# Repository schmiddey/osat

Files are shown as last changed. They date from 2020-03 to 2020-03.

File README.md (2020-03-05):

# osat
Open Source Airsoft Target, WLAN-based Smart Target System

# Overview
The idea of the target system is, that you have one base station (Raspi Pi as WLAN AP) and many target satelites.
The Targets contain a Wemos D1 mini, a Neopixel LED, and a Piezo sensor behind a Polycarbonate plate.

More info is coming !!!

# Process
Currently only the firmware and maybe the hardware is ready or alpha state :)

The Software for the Raspi has to be done next.

note: this was my first try in hardware desigen (KiCAD) and CAD (OpenSCAD) so lets see :)

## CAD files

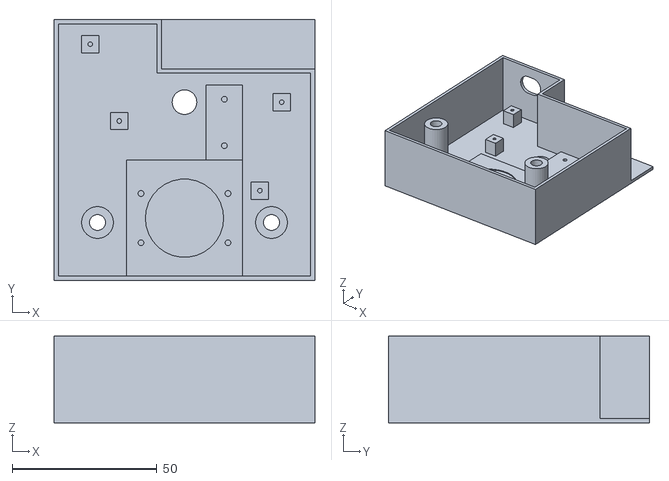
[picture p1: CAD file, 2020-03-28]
cad/stl/osat_base_v1_thinner.stl
90.0 x 90.0 x 30.0

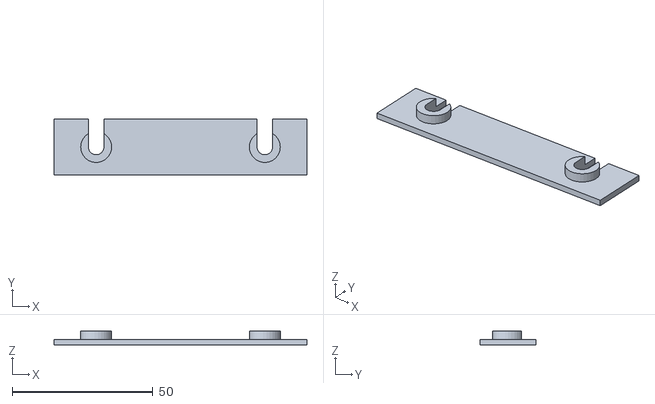
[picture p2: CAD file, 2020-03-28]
cad/stl/osat_base_mount_helper.stl
90.0 x 20.0 x 5.00

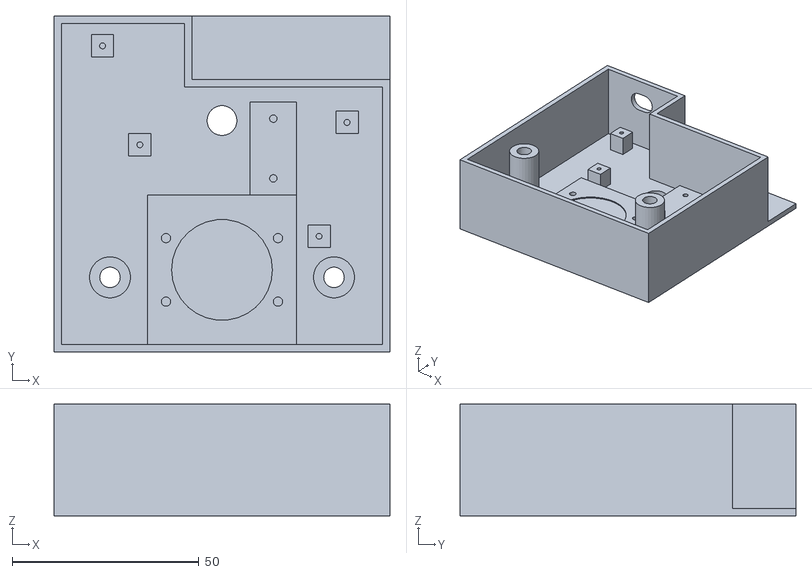
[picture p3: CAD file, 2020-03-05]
cad/stl/osat_base_v1.stl
90.0 x 90.0 x 30.0

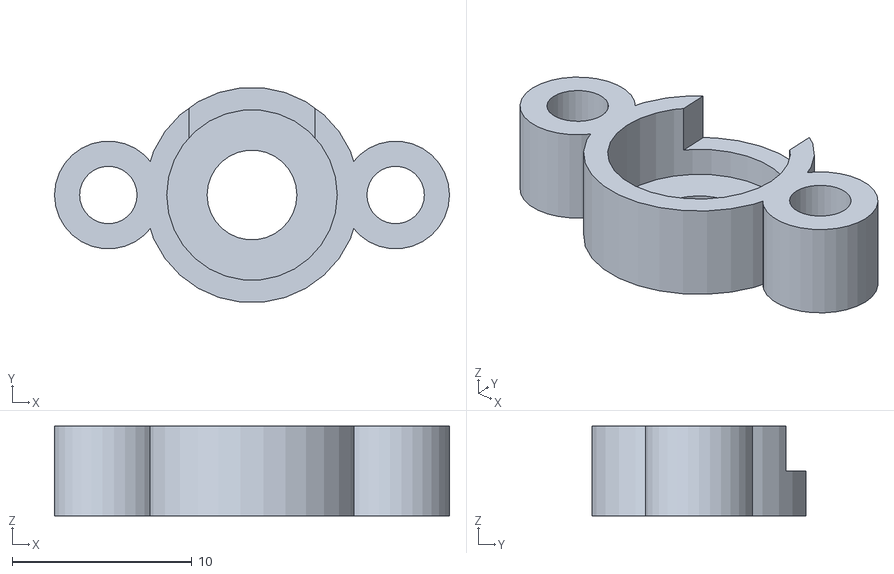
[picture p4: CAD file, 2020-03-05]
cad/stl/WS2812_single_led_mount.stl
22.0 x 11.9 x 5.00

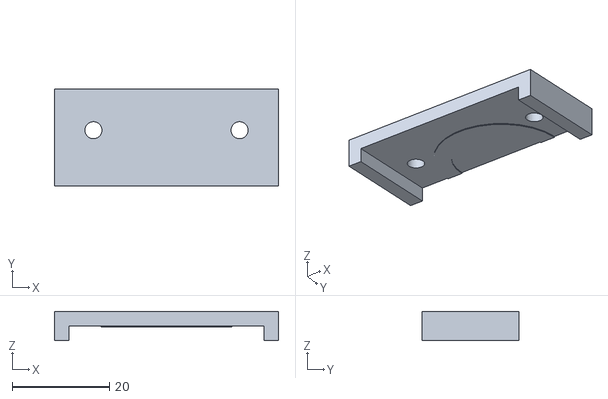
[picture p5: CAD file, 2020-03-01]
cad/stl/osat_piezo_fix.stl
46.0 x 20.0 x 6.00

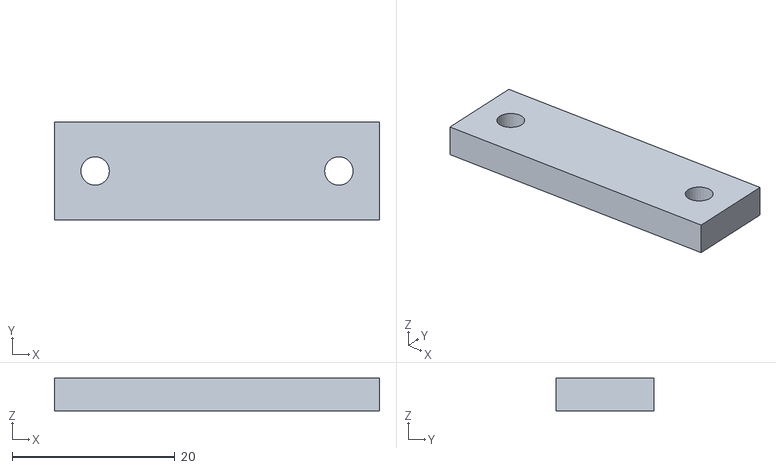
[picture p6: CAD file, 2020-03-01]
cad/stl/osat_piezo_solder_fix.stl
40.0 x 12.0 x 4.00

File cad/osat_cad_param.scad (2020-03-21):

x_length = 90;
y_length = 90;
z_length = 30;

wall_thickness = 1.5;
bottom_thickness = 2;

battery_x_length = 53;
battery_y_length = 17;


glass_mount_hole_diameter = 5.5;
glass_mount_hole_x_dist   = 15;
glass_mount_hole_y_dist   = 20;

piezo_mount_width = 40;
piezo_mount_height = 6;
piezo_y_dist      = 20;
piezo_solder_fix_hole_diameter = 2;
piezo_solder_fix_hole_diameter_2 = 3.5;

piezo_height_step    = 0.2;
piezo_diameter       = 27;
piezo_diameter_inner = 20;

led_mount_width      = 12.5;
led_mount_height     = 5;
led_cable_duct_width = 4;

//param solder mount
x_lenth_solder_mount = 12;


//param piezo_fix
y_length_piezo_fix = 20;


$fs = 0.01;

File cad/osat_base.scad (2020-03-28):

include<osat_cad_param.scad>


union()
{
  difference()
  {
    //main frame
    union()
    {
      difference()
      {
        cube([x_length, y_length, z_length], center = false);
        translate([wall_thickness,wall_thickness,wall_thickness])  cube([x_length - wall_thickness * 2, y_length - wall_thickness * 2 - battery_y_length, 90], center = false);
        translate([wall_thickness,wall_thickness,wall_thickness])  cube([x_length - wall_thickness * 2 - battery_x_length, y_length - wall_thickness * 2, 90], center = false);

        //battery
        translate([x_length - battery_x_length,y_length - battery_y_length,wall_thickness])  cube([x_length, y_length , 90], center = false);
      }
      //mount hole stabilizer
      translate([glass_mount_hole_x_dist, glass_mount_hole_y_dist, 0]) cylinder(d=glass_mount_hole_diameter * 2, h=z_length, center=false);
      translate([x_length - glass_mount_hole_x_dist, glass_mount_hole_y_dist, 0]) cylinder(d=glass_mount_hole_diameter * 2, h=z_length, center=false);
    }

    //mount holes
    #translate([glass_mount_hole_x_dist, glass_mount_hole_y_dist, 0]) cylinder(d=glass_mount_hole_diameter, h=z_length * 2.5, center=true);
    #translate([x_length - glass_mount_hole_x_dist, glass_mount_hole_y_dist, 0]) cylinder(d=glass_mount_hole_diameter, h=z_length * 2.5, center=true);

    //hole for battery connector
    translate([x_length/2, wall_thickness + piezo_mount_width + 20, wall_thickness]) #cylinder(d=8.5, h=z_length * 2.5, center=true);

    //hole for usb conn to wemos
    translate([18,y_length, 19 + wall_thickness]){
      translate([-1.5, 0, 0]) rotate([90,0,0]) #cylinder(d=9, h=z_length, center=true);
      translate([1.5, 0, 0]) rotate([90,0,0]) #cylinder(d=9, h=z_length, center=true);
      rotate([0,90,0]) #cube([9, z_length, 3], center = true);
    }

  }


  //Piezo mount
  translate([x_length/2 - piezo_mount_width/2, wall_thickness, wall_thickness])
  {
    difference()
    {
      cube([piezo_mount_width, piezo_mount_width, piezo_mount_height], center = false);  //piezo mount base
      translate([piezo_mount_width/2, piezo_y_dist, piezo_mount_height - piezo_height_step * 2]) cylinder(d=piezo_diameter, h=100, center=false);   //piezo mount hole
      //holes for screws
      translate([piezo_mount_width/2 - 15, piezo_y_dist + 8.5, 0]) cylinder(d=piezo_solder_fix_hole_diameter, h=100, center=false);
      translate([piezo_mount_width/2 + 15, piezo_y_dist + 8.5, 0]) cylinder(d=piezo_solder_fix_hole_diameter, h=100, center=false);

      translate([piezo_mount_width/2 - 15, piezo_y_dist - 8.5, 0]) cylinder(d=piezo_solder_fix_hole_diameter, h=100, center=false);
      translate([piezo_mount_width/2 + 15, piezo_y_dist - 8.5, 0]) cylinder(d=piezo_solder_fix_hole_diameter, h=100, center=false);
    }

    //just show other stuff in base file
    %translate([0, piezo_y_dist + 8.5 - x_lenth_solder_mount/2, 20])
    {
      include<osat_piezo_solder_fix.scad>
    }

    %translate([-wall_thickness, 0, 20])
    {
      include <osat_piezo_fix.scad>;
    }


  }

  mount_hole = 1.6;

  //led mount base
  translate([x_length/2 + piezo_mount_width/2 - led_mount_width, wall_thickness + piezo_mount_width , wall_thickness])
  {
    y_length_led_mount = y_length - piezo_mount_width - battery_y_length - wall_thickness*2;
    difference()
    {
      cube([led_mount_width, y_length_led_mount - led_cable_duct_width, led_mount_height], center = false);
      translate([led_mount_width / 2, y_length_led_mount / 2 - led_cable_duct_width / 2 + 8, 0]) #cylinder(d = 2, h = led_mount_height * 2, center = false);
      translate([led_mount_width / 2, y_length_led_mount / 2 - led_cable_duct_width / 2 - 8, 0]) #cylinder(d = 2, h = led_mount_height * 2, center = false);
    }
    
    %translate([led_mount_width / 2, y_length_led_mount / 2 - led_cable_duct_width / 2 , 15]){ 
      rotate([180,0,-90]) {include <WS2812_single_led_mount.scad>}
    }   
  }

  board_mount_height = 7;
  //wemose mount
  translate([wall_thickness + 9 + 2, wall_thickness + piezo_mount_width + 40, board_mount_height/2 + wall_thickness]) 
  {
    translate([0, 0, 0]){
      difference() {
        cube([6, 6, board_mount_height], center = true);
        #cylinder(d = mount_hole, h = 30, center = true);
      }
    }
    translate([10, -26.5, 0]){
      difference(){
        cube([6, 6, board_mount_height], center = true);
        #cylinder(d = mount_hole, h = 30, center = true);
      }
    }
    //dbg wemos board
    %translate([-9, -38.5, board_mount_height/2]) cube([26.5, 43, 3], center = false); 
  }

  //dcdc mount
  translate([6 + x_length/2 + piezo_mount_width/2, glass_mount_hole_y_dist + glass_mount_hole_diameter * 2, board_mount_height/2 + wall_thickness]) 
  {
    translate([0, 0, 0]) {
      difference(){
        cube([6, 6, board_mount_height], center = true);
        #cylinder(d = mount_hole, h = 30, center = true);
      }
    } 
    translate([7.5, 30.5, 0]) {
      difference(){
        cube([6, 6, board_mount_height], center = true);
        #cylinder(d = mount_hole, h = 30, center = true);
      }
    }
    %translate([-2.45, -2.45, board_mount_height/2]) cube([17.5, 40.5, 3], center = false);  
  }



}

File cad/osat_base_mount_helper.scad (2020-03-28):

include<osat_cad_param.scad>

x_dist = x_length - glass_mount_hole_x_dist * 2;

difference()
{
  //base
  union()
  {
    cylinder(d = glass_mount_hole_diameter * 2, h = 5, center = false);
    translate([x_dist, 0, 0]) {
      cylinder(d = glass_mount_hole_diameter * 2, h = 5, center = false);
    }
    translate([(x_length - x_dist)/-2, -10, 0]){ cube([x_length, 20, 2], center = false); }
  }
  //holes

  translate([x_dist, 0, 0]) {
      cylinder(d = glass_mount_hole_diameter, h = 25, center = true);
  }
  cylinder(d = glass_mount_hole_diameter, h = 25, center = true);

  //notch
  translate([0, 15, 0]){ cube([glass_mount_hole_diameter, 30, 30], center = true); }
  translate([x_dist, 15, 0]){ cube([glass_mount_hole_diameter, 30, 30], center = true); }

}

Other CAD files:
cad/stl/osat_base_v0.stl
cad/osat_piezo_fix.scad
cad/WS2812_single_led_mount.scad
cad/osat_piezo_solder_fix.scad

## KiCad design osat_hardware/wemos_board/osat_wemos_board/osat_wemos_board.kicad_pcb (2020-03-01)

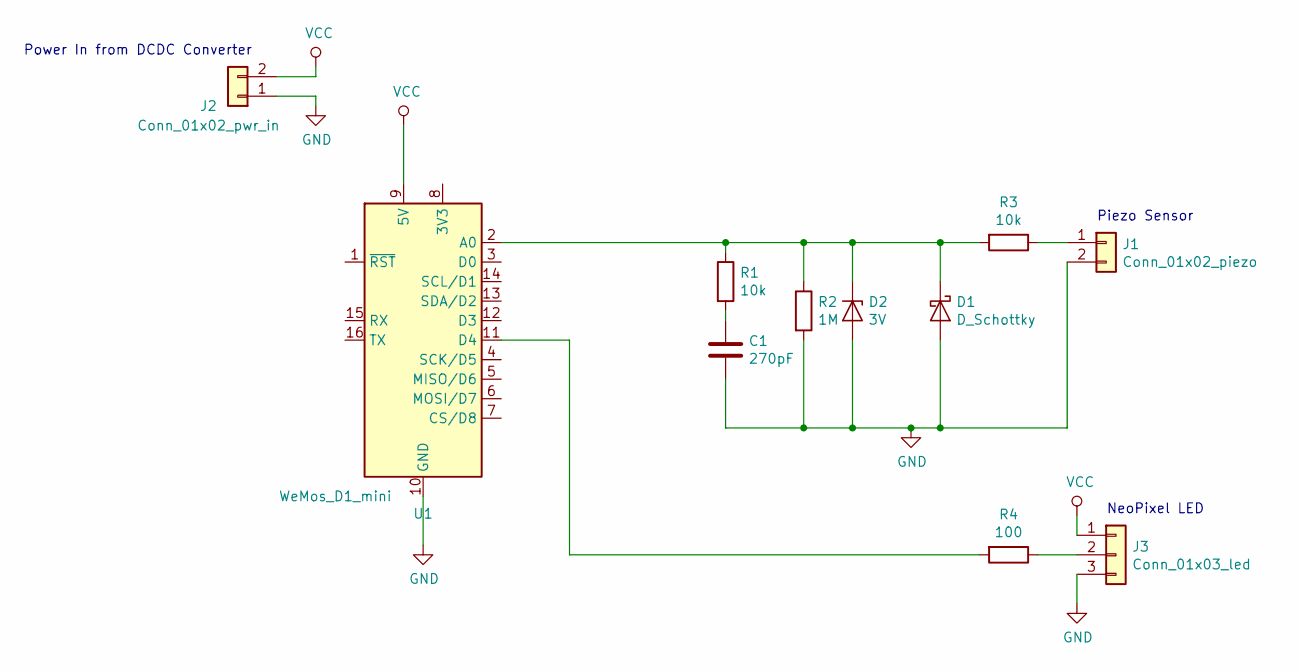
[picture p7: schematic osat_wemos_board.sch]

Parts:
C1: 270pF; C_Disc_D4.3mm_W1.9mm_P5.00mm
D1: D_Schottky; D_A-405_P2.54mm_Vertical_AnodeUp
D2: 3V; D_A-405_P2.54mm_Vertical_AnodeUp
J1: Conn_01x02_piezo; JST_EH_B2B-EH-A_1x02_P2.50mm_Vertical
J2: Conn_01x02_pwr_in; JST_EH_B2B-EH-A_1x02_P2.50mm_Vertical
J3: Conn_01x03_led; JST_EH_B3B-EH-A_1x03_P2.50mm_Vertical
R1, R3: 10k; R_Axial_DIN0204_L3.6mm_D1.6mm_P2.54mm_Vertical
R2: 1M; R_Axial_DIN0204_L3.6mm_D1.6mm_P2.54mm_Vertical
R4: 100; R_Axial_DIN0204_L3.6mm_D1.6mm_P2.54mm_Vertical
U1: WeMos_D1_mini; WEMOS_D1_mini_light

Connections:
GND: C1.1, D1.2 (A), D2.2 (A), J1.2, J2.1, J3.3, R2.2, U1.10 (GND)
unnamed: C1.2, R1.2
unnamed: D1.1 (K), D2.1 (K), R1.1, R2.1, R3.2, U1.2 (A0)
unnamed: J1.1, R3.1
unnamed: J3.2, R4.1
unnamed: R4.2, U1.11 (D4)
VCC: J2.2, J3.1, U1.9 (5V)

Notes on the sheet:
Piezo Sensor
NeoPixel LED
Power In from DCDC Converter

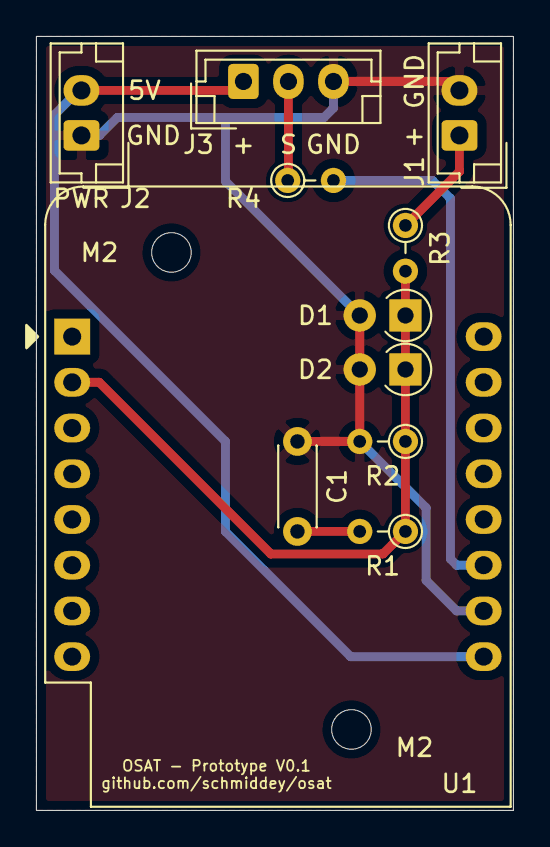
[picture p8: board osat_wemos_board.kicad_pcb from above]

Board: 2 copper layers, 26.5 x 43.0 mm, 13 parts (0 on the bottom side), 7 nets.

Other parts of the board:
M2, M2#2: MountingHole_2.2mm_M2

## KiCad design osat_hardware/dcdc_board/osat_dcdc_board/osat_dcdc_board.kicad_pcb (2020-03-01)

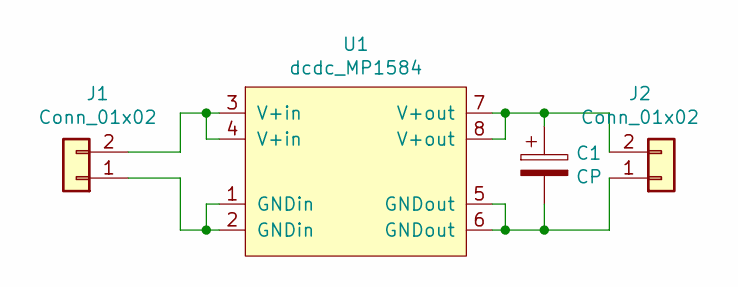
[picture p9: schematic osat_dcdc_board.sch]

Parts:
C1: CP; CP_Radial_D8.0mm_P5.00mm
J1, J2: Conn_01x02; JST_EH_B2B-EH-A_1x02_P2.50mm_Vertical
U1: dcdc_MP1584; MP1584EN_dcdc

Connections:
unnamed: C1.1, J2.2, U1.7 (V+out), U1.8 (V+out)
unnamed: C1.2, J2.1, U1.5 (GNDout), U1.6 (GNDout)
unnamed: J1.1, U1.1 (GNDin), U1.2 (GNDin)
unnamed: J1.2, U1.3 (V+in), U1.4 (V+in)

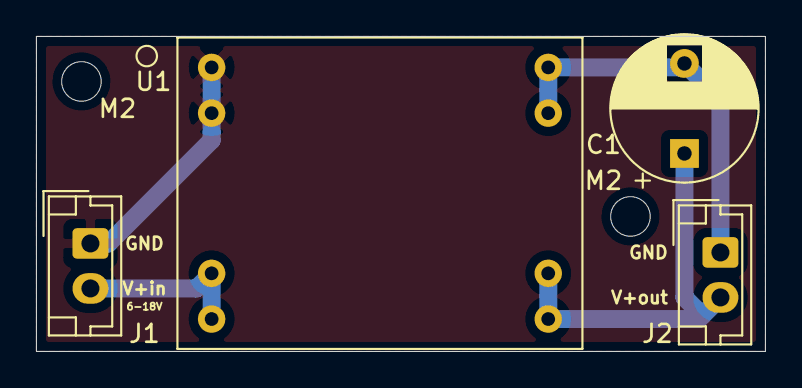
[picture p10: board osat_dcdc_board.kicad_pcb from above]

Board: 2 copper layers, 40.5 x 17.5 mm, 6 parts (0 on the bottom side), 4 nets.

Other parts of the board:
M2, M2#2: MountingHole_2.2mm_M2

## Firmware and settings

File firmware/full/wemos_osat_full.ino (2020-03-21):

#include "Arduino.h"


#include <Adafruit_NeoPixel.h>
#include <ESP8266WiFi.h>
#include <EEPROM.h>
// #include <MQTTClient.h>
#include <WiFiUdp.h>

struct OsatConfig{
  uint8_t    id         = 255;
  uint16_t   hit_thresh = 50;
  uint16_t   timeout_ms = 1500;

  String toString() const
  {
    String str("OsatConfig #id:");
    str += String(id);
    str += String(" #hit_thresh:");
    str += String(hit_thresh);
    str += String(" #timeout_ms:");
    str += String(timeout_ms);
    return str;
  }
};

// https://stackoverflow.com/questions/51731313/cross-platform-crc8-function-c-and-python-parity-check
uint8_t crc8( uint8_t *addr, uint8_t len) {
      uint8_t crc=0;
      for (uint8_t i=0; i<len;i++) {
         uint8_t inbyte = addr[i];
         for (uint8_t j=0;j<8;j++) {
             uint8_t mix = (crc ^ inbyte) & 0x01;
             crc >>= 1;
             if (mix) 
                crc ^= 0x8C;
         inbyte >>= 1;
      }
    }
   return crc;
}

namespace cfg{
  enum Config{
    ID           = 0,
    THRESH_LOW,
    THRESH_HIGH,
    TIMEOUT_LOW,
    TIMEOUT_HIGH,
    CRC,
    CFG_SIZE
  };
}



void write_osat_config(const OsatConfig& cfg)
{
  EEPROM.begin(512);

  uint8_t eeprom_data[cfg::CFG_SIZE];

  eeprom_data[cfg::ID]            = cfg.id;
  eeprom_data[cfg::THRESH_LOW]    = lowByte(cfg.hit_thresh);
  eeprom_data[cfg::THRESH_HIGH]   = highByte(cfg.hit_thresh);
  eeprom_data[cfg::TIMEOUT_LOW]   = lowByte(cfg.timeout_ms);
  eeprom_data[cfg::TIMEOUT_HIGH]  = highByte(cfg.timeout_ms);
  eeprom_data[cfg::CRC]           = crc8(eeprom_data, cfg::CFG_SIZE - 1);
  
  EEPROM.write(cfg::ID,            eeprom_data[cfg::ID]);
  EEPROM.write(cfg::THRESH_LOW,    eeprom_data[cfg::THRESH_LOW]);
  EEPROM.write(cfg::THRESH_HIGH,   eeprom_data[cfg::THRESH_HIGH]);
  EEPROM.write(cfg::TIMEOUT_LOW,   eeprom_data[cfg::TIMEOUT_LOW]);
  EEPROM.write(cfg::TIMEOUT_HIGH,  eeprom_data[cfg::TIMEOUT_HIGH]);
  EEPROM.write(cfg::CRC,           eeprom_data[cfg::CRC]);
  EEPROM.end();
}

OsatConfig read_osat_config()
{
  OsatConfig cfg;

  EEPROM.begin(512);

  uint8_t id            = EEPROM.read(cfg::ID);
  uint8_t thresh_low    = EEPROM.read(cfg::THRESH_LOW);
  uint8_t thresh_high   = EEPROM.read(cfg::THRESH_HIGH);
  uint8_t timeout_low   = EEPROM.read(cfg::TIMEOUT_LOW);
  uint8_t timeout_high  = EEPROM.read(cfg::TIMEOUT_HIGH);

  EEPROM.end();

  cfg.id = id;
  cfg.hit_thresh = word(thresh_high, thresh_low);
  cfg.timeout_ms = word(timeout_high, timeout_low);

  return cfg;
}

/**
 * @brief checks if eeprom_cfg is valid, if not, init with default
 * 
 * @return true is eeprom config is ok, false if not but now valid (with default values)
 */
bool check_osat_config()
{
  uint8_t eeprom_data[cfg::CFG_SIZE];
  
  EEPROM.begin(512);

  eeprom_data[cfg::ID]           = EEPROM.read(cfg::ID);
  eeprom_data[cfg::THRESH_LOW]   = EEPROM.read(cfg::THRESH_LOW);
  eeprom_data[cfg::THRESH_HIGH]  = EEPROM.read(cfg::THRESH_HIGH);
  eeprom_data[cfg::TIMEOUT_LOW]  = EEPROM.read(cfg::TIMEOUT_LOW);
  eeprom_data[cfg::TIMEOUT_HIGH] = EEPROM.read(cfg::TIMEOUT_HIGH);  
  eeprom_data[cfg::CRC]          = EEPROM.read(cfg::CRC);

  EEPROM.end();

  uint8_t tmp_crc = crc8(eeprom_data, cfg::CFG_SIZE - 1);

  if(eeprom_data[cfg::ID] == 0 || tmp_crc != eeprom_data[cfg::CRC])
  {// EEPROM data not valid!!!
    OsatConfig cfg;
    write_osat_config(cfg);
    return false;
  }
  return true;
}



/**
 * @todo ESP.restart(); if needed somewhere :)
 * 
 */

struct Color{
  uint8_t r = 0;
  uint8_t g = 0;
  uint8_t b = 0;
  Color(const uint8_t _r, const uint8_t _g, const uint8_t _b) :
    r(_r), g(_g), b(_b)
  {}
  Color() = default;
};

/**
 * @note  I know its overloaded to implement a class here. But I kind a need it :)
 */
class Led{
public:
  Led()
  {
     _pixel = Adafruit_NeoPixel(1, D4, NEO_GRB + NEO_KHZ800);

     _colors[OFF]     = Color(0,0,0);
     _colors[RED]     = Color(255,0,0);
     _colors[ORANGE]  = Color(255,107,0);
     _colors[GREEN]   = Color(0,255,0);
     _colors[BLUE]    = Color(0,0,255);
     _colors[VIOLETT] = Color(255,0,255);
     _colors[WHITE]  = Color(255,255,255);
  }
  ~Led()
  {}
  
  enum ColorEnum{
    OFF = 0,
    RED,
    ORANGE,
    GREEN,
    BLUE,
    VIOLETT,
    WHITE,
    SIZE
  };

  void init()
  {
    _pixel.begin();
    _pixel.clear();
    this->setColor(OFF);
  }

  /**
   * @brief Set the Color object
   * 
   * @todo add intensity ...
   * 
   * @param color 
   * @param intensity 
   */
  void setColor(const ColorEnum color, const double intensity = 1.0)
  {
    _current_color = color;
    
    double tmp_intens = intensity;
    constrain(tmp_intens, 0.0, 1.0);

    _current_intens = intensity;

    Color c = _colors[color];

    c.r = round(static_cast<double>(c.r) * tmp_intens);
    c.g = round(static_cast<double>(c.g) * tmp_intens);
    c.b = round(static_cast<double>(c.b) * tmp_intens);

    _pixel.setPixelColor(0, _pixel.Color(c.r, c.g, c.b));
    _pixel.show();

  }

  void blink(const ColorEnum color, unsigned long delay_ms = 2, const double intensity = 1.0)
  {
    this->setColor(color, intensity);
    delay(delay_ms); //todo check perfect time :D
    this->setColor(_current_color, _current_intens);
  }

  // void tick()
  // {
  //   _pixel.show();
  // }

private:
  Adafruit_NeoPixel _pixel;

  ColorEnum    _current_color  = Led::OFF;
  double       _current_intens = 1.0;

  Color _colors[SIZE];
};


Led g_led;



/**
 * @brief Communication class for osat server
 * 
 * Comm protocoll for receiving... (All cmds are sended as string...)
 * Commands:
 * "CMD-ACTIVE"    -> Activates OSAT -> waiting for hit... no timeout
 * "CMD-ACTIVE_TO" -> Activates Osat -> waiting for hit, but sets it inactive after timout (from cfg)
 * "CMD-INACTIVE"  -> Deactivates OSAT
 * "CMD-FLASH"     -> Activates Flash Mode -> Flashes when hit
 * 
 * Configs: (All configs are permanently saved in EEPROM)
 * "CFG-ID-xxx"       -> Sets ID of this Module (1..255) 255 default
 * "CFG-THRESH-xxx"   -> Sets hit-threshold for this Module
 * "CFG-TIMEOUT-xxx"  -> Sets timeout in [ms] for ACTIVE_TO mode
 * "CFG-REQUEST"      -> Sends current cfg
 * 
 * @todo add cmd for sending config!!
 * 
 */
class OsatComm{
public:

  enum State {
    IDLE = 0,
    ACTIVE,
    ACTIVE_TO,
    INACTIVE,
    FLASH
  };

  OsatComm(WiFiServer& server) : 
    _server(server)
  { }
  
  ~OsatComm() { }
  
  void connect()
  {
    delay(100);
    // this->transmit("init... check Config...");

    //handle EEPPROM Config
    check_osat_config();

    _osat_config = read_osat_config();
    this->transmit(_osat_config.toString());

  }

  void tickTcpIn()
  {
    if(_server.hasClient())
    {
      _serverClient = _server.available();
      // g_led.blink(Led::VIOLETT, 500);

      // Serial.write("got client");
    }
    int buff_cnt = 0;
    while(true)
    {
      // int mil = millis();
      int av = _serverClient.available();
      // Serial.println(millis() - mil);
      if(!av)
      {
        break;
      }
      _buffer[buff_cnt++] = _serverClient.read();
      // Serial.write(serverClient.read());
    }
    if(buff_cnt)
    {
      _buffer[buff_cnt] = 0; //for safety close string;
      //got cmd.... parse it;
      this->parseCmd(_buffer);
    }
  }

  void sendHit()
  {
    this->transmit("hit\n");
  }

  void sendTimeout()
  {
    this->transmit("timeout");
  }

  void transmit(const String& str) const
  {
    String sendstr(str); //copy
    sendstr = String(_osat_config.id) + String("|") + sendstr;
    //fix endline
    if(!sendstr.endsWith("\n"))
    {
      sendstr += '\n';
    }

    {
      WiFiClient cl;
      while(!cl.connect(_SERVER, _PORT))
      {
        optimistic_yield(100);
      }
      cl.setNoDelay(true);
      cl.setSync(false);
      cl.disableKeepAlive();
      delay(5);
      // optimistic_yield(10000);
      cl.print(sendstr.c_str());
      // cl.flush(100);
      // optimistic_yield(10000);
    }
    delay(5);
  }

  State getState() const
  {
    return _state;
  }

  void setState(const State state)
  {
    _state = state;
  }

  const OsatConfig& getConfig() const
  {
    return _osat_config;
  }

  bool checkHit()
  {
    int piezo = analogRead(A0);
    delay(9);  //very important here -> if not there wifi will disconnect ... sadly :(
  
    if(piezo > _osat_config.hit_thresh)
    {
      return true;
    }
    return false;
  }

private: //functions

  void parseCmd(const char* data)
  {
    String msg(data);
    String msg_type    = msg.substring(0,3);
    String msg_contend = msg.substring(4);

    // this->transmit(msg_type.c_str());
    // this->transmit(msg_contend.c_str());
    
    //remove \n from msg_contend
    if(msg_contend.endsWith("\n"))
    {
      //remove \n
      msg_contend.remove(msg_contend.length() -1);
    }

    bool cmd_ok = false;
    bool cfg_ok = false;

    //decide if cmd or cfg... 
    if(msg_type == String("CMD"))
    {
      if(msg_contend == String("ACTIVE"))
      {
        this->setState(ACTIVE);
        cmd_ok = true;
      }
      else if(msg_contend == String("ACTIVE_TO"))
      {
        this->setState(ACTIVE_TO);
        cmd_ok = true;
      }
      else if(msg_contend == String("INACTIVE"))
      {
        this->setState(INACTIVE);
        cmd_ok = true;
      }
      else if(msg_contend == String("FLASH"))
      {
        this->setState(FLASH);
        cmd_ok = true;
      }
      //invalid
    }
    else if(msg_type == String("CFG"))
    {
      //CFG-ID-xxx
      //CFG-THRESH-xxx
      //CFG-TIMEOUT-xxx
      if(msg_contend.substring(0,2) == String("ID"))
      {
        //set id
        unsigned int tmp_id = msg_contend.substring(3).toInt();
        if(tmp_id && tmp_id <=255)
        {  
          _osat_config.id = static_cast<uint8_t>(tmp_id);
          write_osat_config(_osat_config);
          cfg_ok = true;
        }
      }
      else if(msg_contend.substring(0,6) == String("THRESH"))
      {
        unsigned int tmp_thresh = msg_contend.substring(7).toInt();
        if(tmp_thresh &&tmp_thresh <= 1023)
        {  
          _osat_config.hit_thresh = tmp_thresh;
          write_osat_config(_osat_config);
          cfg_ok = true;
        }
      }
      else if(msg_contend.substring(0,7) == String("TIMEOUT"))
      {
        unsigned int tmp_timeout = msg_contend.substring(8).toInt();
        if(tmp_timeout && tmp_timeout <=10000)
        {  
          _osat_config.timeout_ms = tmp_timeout;
          write_osat_config(_osat_config);
          cfg_ok = true;
        }
      }
      else if(msg_contend.substring(0,8) == String("REQUEST"))
      {
        //only request cfg
        cfg_ok = true;
      }
    }

    if(cmd_ok)
    {
      //send ack
      // this->transmit(msg);
    }
    else if(cfg_ok)
    {
      //send ack
      // this->transmit(msg);
      //send new config
      this->transmit(_osat_config.toString());
    }
    else  //invalid command
    {
      this->transmit("Got invalid Command ...");
    }
    //For ack  
    // this->transmit(data);
  }
  
private:
  WiFiServer& _server;        //tcp server;
  WiFiClient  _serverClient;  //only one client for server


  const char*    _SERVER = "192.168.5.1";
  // const char*    _SERVER = "10.42.0.1";
  const uint16_t _PORT   = 1337;

  char _buffer[50];

  State _state = IDLE;

  OsatConfig _osat_config;
};

WiFiServer g_wifiserver(1335);


//router @ home
const auto ssid = "osat_base";
const auto pass = "1234567890";
// const auto ssid = "schmiddeys_WWW";
// const auto pass = "1234567890";

// // think ap
// const auto ssid = "think";
// const auto pass = "NPWZtluM";

OsatComm g_osat_com(g_wifiserver);




void setup() 
{
  // bool ret_check_cfg = check_osat_config();

  // g_osat_config = read_osat_config();

  WiFi.begin(ssid, pass);

  g_led.init();

  g_led.setColor(Led::RED);

  while (WiFi.status() != WL_CONNECTED) {
    g_led.setColor(Led::BLUE);
    delay(250);
    g_led.setColor(Led::OFF);
    delay(250);
  }


  g_wifiserver.begin();
  g_wifiserver.setNoDelay(true);

  // WiFi.setAutoReconnect(true);
  g_led.setColor(Led::GREEN);
  delay(1000);

  //osat com
  g_osat_com.connect();

  g_led.setColor(Led::VIOLETT);
  delay(1000);
}

int cnt = 0;

OsatComm::State old_state = OsatComm::IDLE;

uint32_t timeout = 0;

void loop() 
{
  g_osat_com.tickTcpIn();

  switch(g_osat_com.getState()) {
    case OsatComm::ACTIVE:
    {
      //detect state change flag
      if(old_state != OsatComm::ACTIVE)
      {
        g_led.setColor(Led::ORANGE);
      }
      
      old_state = OsatComm::ACTIVE;

      if(g_osat_com.checkHit())
      {//got hit
        //LED off
        g_led.setColor(Led::OFF);
        //send hit
        g_osat_com.sendHit();

        //set inactive
        g_osat_com.setState(OsatComm::INACTIVE);
      } 
      break;
    }
    case OsatComm::ACTIVE_TO:
    {
      //detect state change flag
      if(old_state != OsatComm::ACTIVE_TO)
      {
        g_led.setColor(Led::RED);
        //start timer
        timeout = millis();
      }
      
      old_state = OsatComm::ACTIVE_TO;

      //check timeout
      if((millis() - timeout) > g_osat_com.getConfig().timeout_ms)
      {
        //got timeout
        g_led.setColor(Led::OFF);

        g_osat_com.sendTimeout();

        g_osat_com.setState(OsatComm::INACTIVE);
        break;
      }

      if(g_osat_com.checkHit())
      {//got hit
        //LED off
        g_led.setColor(Led::OFF);
        //send hit
        g_osat_com.sendHit();

        //set inactive
        g_osat_com.setState(OsatComm::INACTIVE);
      } 
      break;
    }
    case OsatComm::INACTIVE:
    {
      if(old_state != OsatComm::INACTIVE)
      {

        g_led.setColor(Led::OFF);
      }
      //do nothing
      old_state = OsatComm::INACTIVE;
      delay(5);
      break;
    }
    case OsatComm::FLASH:
    {
      if(old_state != OsatComm::FLASH)
      {
        //led WHITE
        g_led.setColor(Led::WHITE, 0.1);
      }

      old_state = OsatComm::FLASH;
      
      
      if(g_osat_com.checkHit())
      {
        g_osat_com.sendHit();
        g_led.setColor(Led::GREEN);
        delay(50);
        g_led.setColor(Led::OFF);
        delay(100);
        g_led.setColor(Led::WHITE, 0.1);
      }
      break;
    }
    default: //idle
    {
      if(cnt%100 == 0)
      {
        g_led.setColor(Led::VIOLETT);
        delay(10);
        g_led.setColor(Led::OFF);
        // delay(50);
        //send config
        g_osat_com.transmit(g_osat_com.getConfig().toString());
        delay(10);
        g_osat_com.transmit(String(WiFi.RSSI()));
        

      }
      delay(10);
      break;
    }
  }
 
 
  ++cnt;
}

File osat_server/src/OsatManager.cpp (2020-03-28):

#include "OsatManager.h"

namespace{
  const uint32_t OSAT_SERVER_PORT = 1337;
}

namespace osat{


OsatManager::OsatManager() :
  _tcp_server(OSAT_SERVER_PORT)
{
  _tcp_server.attach_read_callback(std::bind(&OsatManager::tcp_in_callback, this, std::placeholders::_1, std::placeholders::_2));
}

OsatManager::~OsatManager()
{ }

void OsatManager::start(const bool scan_for_clients)
{
  std::cout << "start tcp" << std::endl;
  _tcp_server.start();
  if(scan_for_clients)
  {
    std::cout << "find clients: " << std::endl;
    // Duration d(1.0);
    this->findClients();
  }
}

void OsatManager::stop()
{
  _run = false;
}


void OsatManager::spin()
{
  // _tcp_server.spin();
  while(_run.load())
  {
    _tcp_server.spinOnce();
    _mode->tick();
    //delay
    std::this_thread::sleep_for(std::chrono::microseconds(1000));
  }
}

void OsatManager::spinOnce()
{
  _tcp_server.spinOnce();
  if(_mode)
  {
    _mode->tick();
  }
}

void OsatManager::startMode(std::weak_ptr<Mode> mode)
{
  if(mode.expired())
  {
    std::cout << "Warning: given mode is expired..." << std::endl;
    return;
  }

  _mode = mode.lock();

  //attach callbacks
  _mode->attach_state_change_callback(std::bind(&OsatManager::setOsatState, this, std::placeholders::_1, std::placeholders::_2));
  _mode->attach_mode_ready_callback(std::bind(&OsatManager::modeRdy_callback, this, std::placeholders::_1, std::placeholders::_2));
  _mode->attach_change_timeout_callback(std::bind(&OsatManager::setOsatTimeout, this, std::placeholders::_1, std::placeholders::_2));

  _mode->start();

}

void OsatManager::stopMode(const std::string& mode_name)
{
  _mode->reset();
}

void OsatManager::modeRdy_callback(const std::string& mode_name, const Report& rep)
{
  std::cout << "Mode Rdy: " << rep << std::endl;
}


ClientList& OsatManager::getClientList() 
{
  return _clients;
}

void OsatManager::setOsatState(const uint8_t id, const state::OsatState state)
{
  if(!_clients.contains(id))
  {
    std::cout << "Requested id not available" << std::endl;
    return;
  }
  for(auto& e : _clients.at(id))
  {
    OsatCommand::write_to(e.first, OsatCommand::create_set_state_cmd(state));
  }
}


void OsatManager::setOsatTimeout(const uint8_t id, const uint32_t timeout_ms)
{
  if(!_clients.contains(id))
  {
    std::cout << "Requested id not available" << std::endl;
    return;
  }

  for(auto& e : _clients.at(id))
  {
    OsatCommand::write_to(e.first, OsatCommand::create_cfg_timeout_cmd(timeout_ms));
  }
}


void OsatManager::setOsatThreshAll(const uint32_t thresh)
{
  for(auto& e : _clients.get_container())
  {
    for(auto& f : e.second)
    {
      OsatCommand::write_to(f.first, OsatCommand::create_cfg_thresh_cmd(thresh));
    }
  }
}


void OsatManager::setConfig(const uint8_t id, const OsatConfig& cfg)
{
  if(!_clients.contains(id))
  {
    std::cout << "Requested id not available" << std::endl;
    return;
  }


  for(auto& e : _clients.at(id))
  {
    //send cfg
    //only send if something is different than old cfg
    
    //send new id
    if(e.second.cfg.id != cfg.id)
    {
      OsatCommand::write_to(e.first, OsatCommand::create_cfg_id_cmd(cfg.id));
    }
    //send new thresh
    if(e.second.cfg.hit_thresh != cfg.hit_thresh)
    {
      OsatCommand::write_to(e.first, OsatCommand::create_cfg_thresh_cmd(cfg.hit_thresh));
    }
    //for now dont set timeout in default config set.... is set by mode
    // //send new timeout
    // if(e.second.cfg.timeout_ms != cfg.timeout_ms)
    // {
    //   OsatCommand::write_to(e.first, OsatCommand::create_cfg_timeout_cmd(cfg.timeout_ms));
    // }
  }

}

std::optional<OsatConfig> OsatManager::getConfig(const uint8_t id)
{
  if(!_clients.contains(id))
  {
    return std::nullopt;
  }
  //return config //if multiple clients per id just return first one (should all the same by definition)
  return _clients.at(id).begin()->second.cfg;
}



void OsatManager::findClients()
{
  std::cout << "try finding active Clients..." << std::endl;
  std::vector<std::thread> thrds(253);
  std::atomic<std::size_t> num_thrds = 0;
  Duration d(0.005);
  for(unsigned int i = 2; i < 255; i++)
  {
    std::string ip = "192.168.5." + std::to_string(i);
    while(num_thrds.load() >= 100)
    {
      d.sleep();
    }
    // std::cout << "ip: " << ip << std::endl;
    thrds[i-2] = std::thread([&num_thrds, ip]() {
      num_thrds++;
      //request config
      OsatCommand::write_to(ip, OsatCommand::create_cfg_request());
      num_thrds--;
    });

    thrds[i-2].detach();
  }

  while(num_thrds.load() != 0)
  {
    d.sleep();
  }


  std::cout << "running threads: " << num_thrds.load() << std::endl;
  std::cout << "searching for clients rdy" << std::endl;
}

void OsatManager::tcp_in_callback(const osat::server::ClientEndpoint& ce, const std::string& data)
{
  //extract id from data
  std::cout << "-----------          data: " << data << std::endl; 

  std::string id_str  = data.substr(0, data.find('|'));
  std::string payload = data.substr(data.find('|') +1, data.length());
  
  std::cout << "id_str: " << id_str << std::endl;
  std::cout << "payload: " << payload << std::endl;
  
  uint8_t id = 0;
  try{
    id = boost::lexical_cast<uint32_t>(id_str);
  }catch(const boost::bad_lexical_cast& e)
  {
    std::cerr << "error at received data: " << e.what() << '\n';
    return;
  }
  

  //only init if config is received
  if(OsatConfig::isConfig(payload))
  {
    //parse config
    OsatConfig cfg(payload);
    if(!cfg)
    {
      //nothing to do ... broken config;
      return;
    }
    ClientInfo ci(ce.ip, cfg);
    //prove if client is in list if not insert it
    if(_clients.insert(id, ci))
    {
      std::cout << "Got new Client: " << ce.to_string() << ", with config: " << cfg << std::endl;

      //show current client list
      std::cout << "Current client list: " << _clients.to_string() << std::endl;
      return;
    }

    //alread in list -> update config
    _clients.update_config(cfg, id, ce.ip);
    return;
  }
  else
  {
    //is client not in list and no Config is sent then request config
    if(!_clients.contains(id, ce.ip))
    {
      //request config
      if(!OsatCommand::write_to(ce.ip, OsatCommand::create_cfg_request()))
      {
        std::cout << "Unable to write Msg to: " << ce.ip << std::endl;
      }
    }
  }
  if(!_mode)
  {
    return;
  }
  //parse other commands
  if(payload == std::string("hit"))
  {
    _mode->setAction(id, action::HIT);
  }
  else if(payload == std::string("timeout"))
  {
    _mode->setAction(id, action::TIMEOUT);
  }
  else if(payload == std::string("Got invalid Command ..."))
  {
    std::cout << "Warning -> Osat with id: " << id << ", ip: " << ce.ip << " got an ivalid command from server" <<  std::endl;
  }
  else
  {
    //other command only show nothing to do
    std::cout << "Got msg from Osat id: " << id << ", ip: " << ce.ip << " -> : " << data << std::endl;
  }



}




} //namespace osat

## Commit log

2020-03-01 init push
    [osat_base.scad, osat_base_v0.stl, osat_cad_param.scad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]
2020-03-05 updated CAD model (but hacked :D ) added mounts for pcp and added holes for wemos usb port and 5.5mm power con
    [WS2812_single_led_mount.scad, WS2812_single_led_mount.stl, osat_base.scad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]
2020-03-21 minor changes overall... first commit with osat_server and osat_clients working (3 modes)
    [osat_base.scad, osat_base_v1_thinner.stl, osat_cad_param.scad]
2020-03-28 added modes working correctly, added scan for osats, alpha state of osat_server_terminal
    [osat_base.scad, osat_base_mount_helper.scad, osat_base_mount_helper.stl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]
